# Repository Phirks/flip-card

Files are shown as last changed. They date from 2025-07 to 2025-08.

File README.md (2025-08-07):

This repo contains all files related to the flip-card project, which is a business card that runs a fluid-implicit-particle(FLIP) simulation.



The PCB design files are in the "kicad-pcb" folder. The flip-card project is inspired by mitxela's fluid simulation pendant project https://mitxela.com/projects/fluid-pendant

The fluid simulation logic is contained in a standalone crate, which is in the "fluid_sim_crate" folder. This is based off the work by Matthias Müller (https://github.com/matthias-research) and his excelent demonstrations on his youtube channel "Ten Minute Physics"

One of the more difficult features was the rechargable battery.  I found a design for a board edge usb-c port from cnlohr's tiny touch lcd project https://github.com/cnlohr/ch32v003_3digit_lcd_usb/

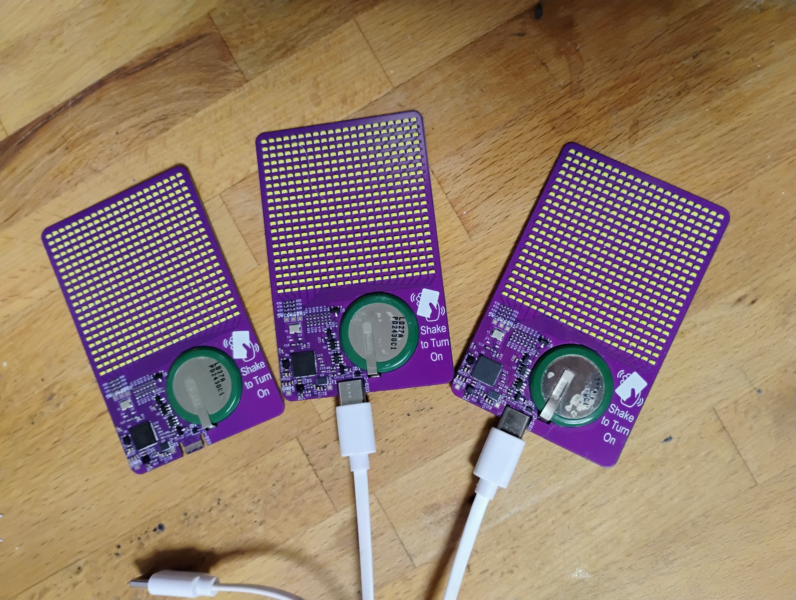
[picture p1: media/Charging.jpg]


a WASM simulator is also provided in the "sim_display" folder, which is what I use to debug issues in the simulation.

The implementation for the fluid simulation on the rp2350 is in the "flip-card_firmware" file

further details can be found in each folder's README files

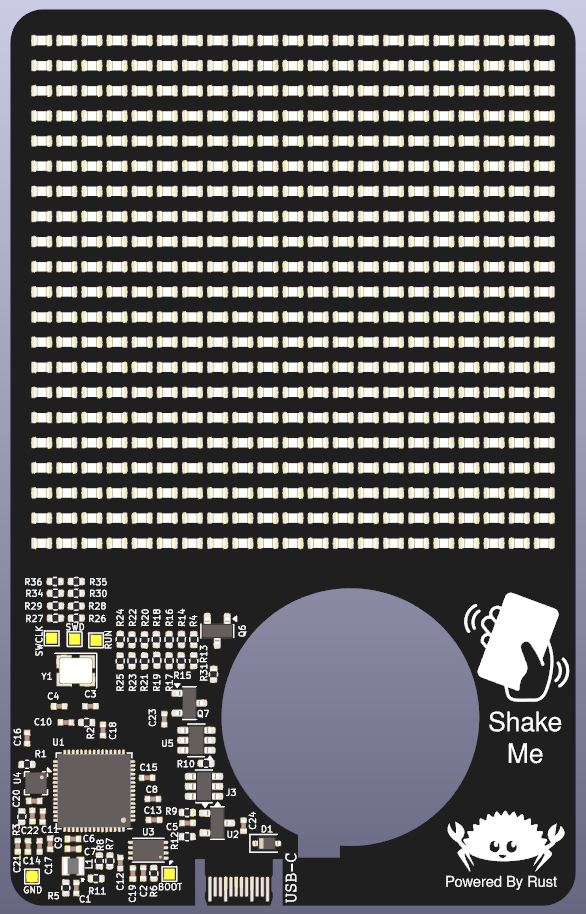
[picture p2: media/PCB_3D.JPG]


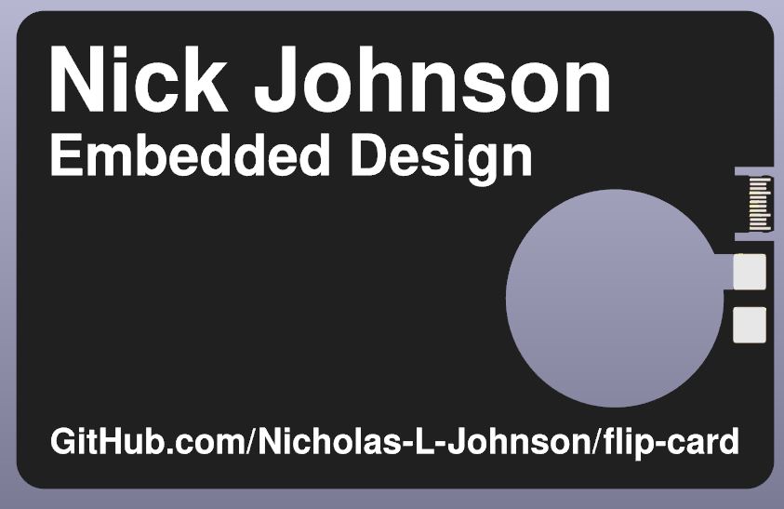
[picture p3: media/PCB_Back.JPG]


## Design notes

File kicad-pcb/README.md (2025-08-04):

Here are the PCB design files. KiCad 8.0 or higher required.

The gerber, BOM, and centroid files are in the "Production Files" directory

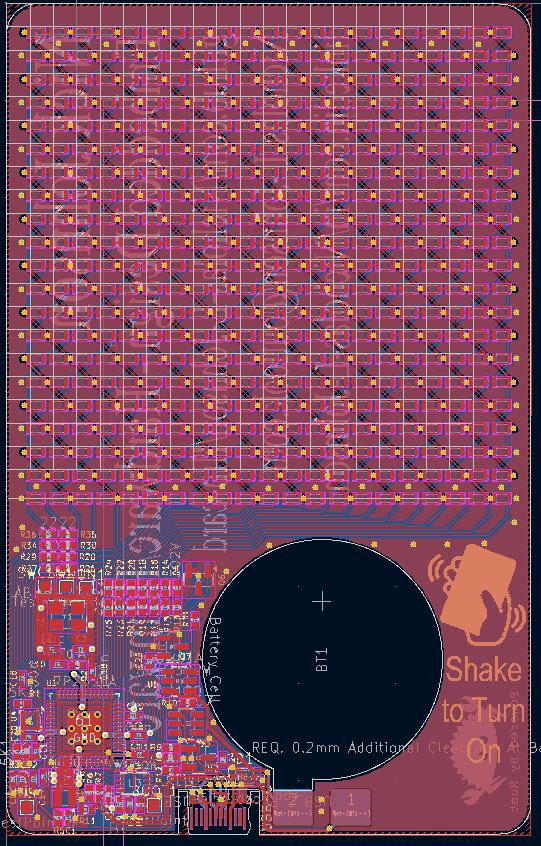
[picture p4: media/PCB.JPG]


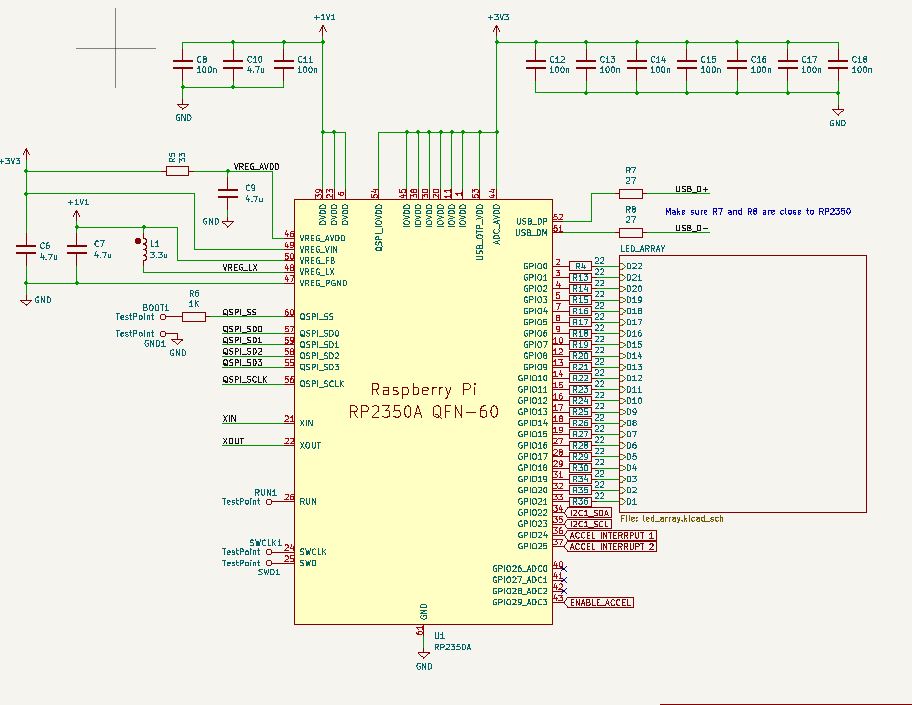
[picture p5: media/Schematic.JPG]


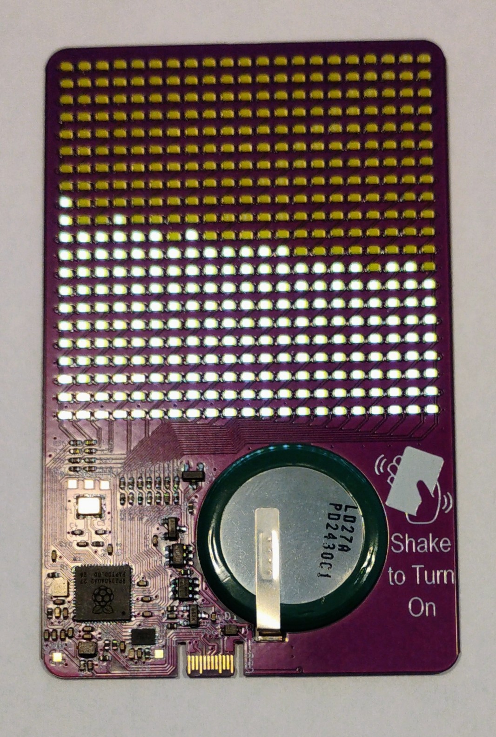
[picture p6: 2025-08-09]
media/IMG_20250809_132234644_AE.jpg

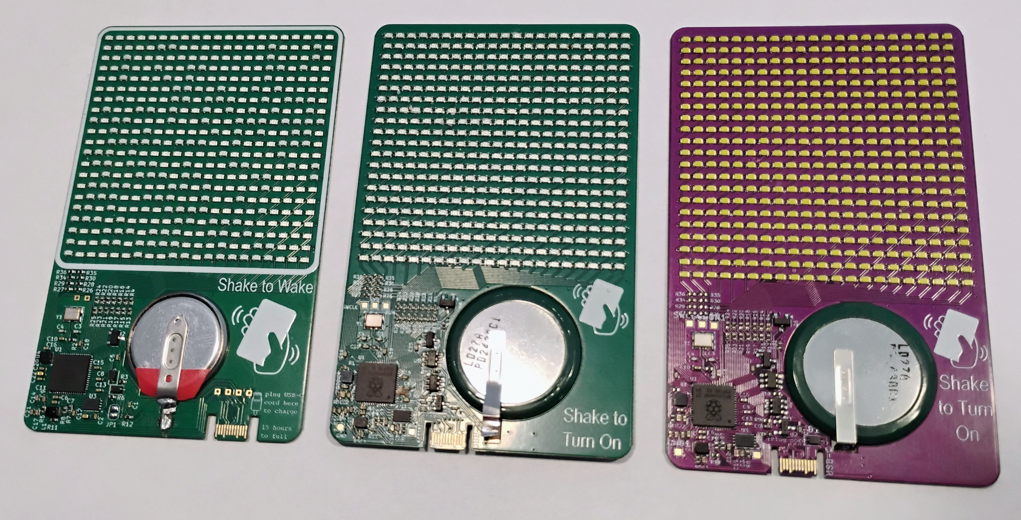
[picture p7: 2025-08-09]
media/IMG_20250809_134121077_AE.jpg

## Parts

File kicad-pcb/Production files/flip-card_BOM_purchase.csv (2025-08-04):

Comment | Designator | Footprint | JLCPCB Part +ACP/CA-optional+/wk-
1u | C1 | 402 | C2887021
100n | C2 | 402 | C5137468
15p | C3 | 402 | C326803
15p | C4 | 402 | C326803
1u | C5 | 402 | C2887021
4.7u | C6 | 402 | C380302
4.7u | C7 | 402 | C380302
100n | C8 | 402 | C5137468
4.7u | C9 | 402 | C380302
4.7u | C10 | 402 | C380302
100n | C11 | 402 | C5137468
100n | C12 | 402 | C5137468
100n | C13 | 402 | C5137468
100n | C14 | 402 | C5137468
100n | C15 | 402 | C5137468
100n | C16 | 402 | C5137468
100n | C17 | 402 | C5137468
100n | C18 | 402 | C5137468
10u | C19 | 402 | C76991
100n | C20 | 402 | C5137468
100n | C21 | 402 | C5137468
10u | C22 | 402 | C76991
100n | C23 | 402 | C5137468
1u | C24 | 402 | C2887021
Schottky Diode | D1 | SOD+AC0-323 | C146335
LED | D101 | 603 | C497920
LED | D102 | 603 | C497920
LED | D103 | 603 | C497920
LED | D104 | 603 | C497920
LED | D105 | 603 | C497920
LED | D106 | 603 | C497920
LED | D107 | 603 | C497920
LED | D108 | 603 | C497920
LED | D109 | 603 | C497920
LED | D110 | 603 | C497920
LED | D111 | 603 | C497920
LED | D112 | 603 | C497920
LED | D113 | 603 | C497920
LED | D114 | 603 | C497920
LED | D115 | 603 | C497920
LED | D116 | 603 | C497920
LED | D117 | 603 | C497920
LED | D118 | 603 | C497920
LED | D119 | 603 | C497920
LED | D120 | 603 | C497920
LED | D121 | 603 | C497920
LED | D122 | 603 | C497920
LED | D123 | 603 | C497920
LED | D124 | 603 | C497920
LED | D125 | 603 | C497920
LED | D126 | 603 | C497920
LED | D127 | 603 | C497920
LED | D128 | 603 | C497920
LED | D129 | 603 | C497920
LED | D130 | 603 | C497920
LED | D131 | 603 | C497920
LED | D132 | 603 | C497920
LED | D133 | 603 | C497920
LED | D134 | 603 | C497920
LED | D135 | 603 | C497920
LED | D136 | 603 | C497920
LED | D137 | 603 | C497920
LED | D138 | 603 | C497920
LED | D139 | 603 | C497920
LED | D140 | 603 | C497920
LED | D141 | 603 | C497920
LED | D142 | 603 | C497920
LED | D143 | 603 | C497920
LED | D144 | 603 | C497920
LED | D145 | 603 | C497920
LED | D146 | 603 | C497920
LED | D147 | 603 | C497920
LED | D148 | 603 | C497920
LED | D149 | 603 | C497920
LED | D150 | 603 | C497920
LED | D151 | 603 | C497920
LED | D152 | 603 | C497920
LED | D153 | 603 | C497920
LED | D154 | 603 | C497920
LED | D155 | 603 | C497920
LED | D156 | 603 | C497920
LED | D157 | 603 | C497920
LED | D158 | 603 | C497920
LED | D159 | 603 | C497920
LED | D160 | 603 | C497920
LED | D161 | 603 | C497920
LED | D162 | 603 | C497920
LED | D163 | 603 | C497920
LED | D164 | 603 | C497920
LED | D165 | 603 | C497920
LED | D166 | 603 | C497920
LED | D167 | 603 | C497920
LED | D168 | 603 | C497920
LED | D169 | 603 | C497920
LED | D170 | 603 | C497920
LED | D171 | 603 | C497920
LED | D172 | 603 | C497920
LED | D173 | 603 | C497920
LED | D174 | 603 | C497920
LED | D175 | 603 | C497920
LED | D176 | 603 | C497920
LED | D177 | 603 | C497920
LED | D178 | 603 | C497920
LED | D179 | 603 | C497920
LED | D180 | 603 | C497920
LED | D181 | 603 | C497920
LED | D182 | 603 | C497920
LED | D183 | 603 | C497920
LED | D184 | 603 | C497920
LED | D185 | 603 | C497920
LED | D186 | 603 | C497920
LED | D187 | 603 | C497920
LED | D188 | 603 | C497920
LED | D189 | 603 | C497920
LED | D190 | 603 | C497920
LED | D191 | 603 | C497920
LED | D192 | 603 | C497920
LED | D193 | 603 | C497920
LED | D194 | 603 | C497920
LED | D195 | 603 | C497920
LED | D196 | 603 | C497920
LED | D197 | 603 | C497920
LED | D198 | 603 | C497920
LED | D199 | 603 | C497920
LED | D200 | 603 | C497920
LED | D201 | 603 | C497920
LED | D202 | 603 | C497920
LED | D203 | 603 | C497920
LED | D204 | 603 | C497920
LED | D205 | 603 | C497920
LED | D206 | 603 | C497920
LED | D207 | 603 | C497920
LED | D208 | 603 | C497920
LED | D209 | 603 | C497920
LED | D210 | 603 | C497920
LED | D211 | 603 | C497920
LED | D212 | 603 | C497920
LED | D213 | 603 | C497920
LED | D214 | 603 | C497920
LED | D215 | 603 | C497920
LED | D216 | 603 | C497920
LED | D217 | 603 | C497920
LED | D218 | 603 | C497920
LED | D219 | 603 | C497920
LED | D220 | 603 | C497920
LED | D221 | 603 | C497920
LED | D222 | 603 | C497920
LED | D223 | 603 | C497920
LED | D224 | 603 | C497920
LED | D225 | 603 | C497920
LED | D226 | 603 | C497920
LED | D227 | 603 | C497920
LED | D228 | 603 | C497920
LED | D229 | 603 | C497920
LED | D230 | 603 | C497920
LED | D231 | 603 | C497920
LED | D232 | 603 | C497920
LED | D233 | 603 | C497920
LED | D234 | 603 | C497920
LED | D235 | 603 | C497920
LED | D236 | 603 | C497920
LED | D237 | 603 | C497920
LED | D238 | 603 | C497920
LED | D239 | 603 | C497920
LED | D240 | 603 | C497920
LED | D241 | 603 | C497920
LED | D242 | 603 | C497920
LED | D243 | 603 | C497920
LED | D244 | 603 | C497920
LED | D245 | 603 | C497920
LED | D246 | 603 | C497920
LED | D247 | 603 | C497920
LED | D248 | 603 | C497920
LED | D249 | 603 | C497920
LED | D250 | 603 | C497920
LED | D251 | 603 | C497920
LED | D252 | 603 | C497920
LED | D253 | 603 | C497920
LED | D254 | 603 | C497920
LED | D255 | 603 | C497920
LED | D256 | 603 | C497920
LED | D257 | 603 | C497920
LED | D258 | 603 | C497920
LED | D259 | 603 | C497920
LED | D260 | 603 | C497920
LED | D261 | 603 | C497920
LED | D262 | 603 | C497920
LED | D263 | 603 | C497920
LED | D264 | 603 | C497920
LED | D265 | 603 | C497920
LED | D266 | 603 | C497920
LED | D267 | 603 | C497920
LED | D268 | 603 | C497920
LED | D269 | 603 | C497920
LED | D270 | 603 | C497920
LED | D271 | 603 | C497920
LED | D272 | 603 | C497920
LED | D273 | 603 | C497920
LED | D274 | 603 | C497920
LED | D275 | 603 | C497920
LED | D276 | 603 | C497920
LED | D277 | 603 | C497920
LED | D278 | 603 | C497920
LED | D279 | 603 | C497920
LED | D280 | 603 | C497920
LED | D281 | 603 | C497920
LED | D282 | 603 | C497920
LED | D283 | 603 | C497920
LED | D284 | 603 | C497920
LED | D285 | 603 | C497920
LED | D286 | 603 | C497920
LED | D287 | 603 | C497920
LED | D288 | 603 | C497920
LED | D289 | 603 | C497920
LED | D290 | 603 | C497920
LED | D291 | 603 | C497920
LED | D292 | 603 | C497920
LED | D293 | 603 | C497920
LED | D294 | 603 | C497920
LED | D295 | 603 | C497920
LED | D296 | 603 | C497920
LED | D297 | 603 | C497920
LED | D298 | 603 | C497920
LED | D299 | 603 | C497920
LED | D300 | 603 | C497920
LED | D301 | 603 | C497920
LED | D302 | 603 | C497920
LED | D303 | 603 | C497920
LED | D304 | 603 | C497920
LED | D305 | 603 | C497920
LED | D306 | 603 | C497920
LED | D307 | 603 | C497920
LED | D308 | 603 | C497920
LED | D309 | 603 | C497920
LED | D310 | 603 | C497920
LED | D311 | 603 | C497920
LED | D312 | 603 | C497920
LED | D313 | 603 | C497920
LED | D314 | 603 | C497920
LED | D315 | 603 | C497920
LED | D316 | 603 | C497920
LED | D317 | 603 | C497920
LED | D318 | 603 | C497920
LED | D319 | 603 | C497920
LED | D320 | 603 | C497920
LED | D321 | 603 | C497920
LED | D322 | 603 | C497920
LED | D323 | 603 | C497920
LED | D324 | 603 | C497920
LED | D325 | 603 | C497920
LED | D326 | 603 | C497920
LED | D327 | 603 | C497920
LED | D328 | 603 | C497920
LED | D329 | 603 | C497920
LED | D330 | 603 | C497920
LED | D331 | 603 | C497920
LED | D332 | 603 | C497920
LED | D333 | 603 | C497920
LED | D334 | 603 | C497920
LED | D335 | 603 | C497920
LED | D336 | 603 | C497920
LED | D337 | 603 | C497920
LED | D338 | 603 | C497920
LED | D339 | 603 | C497920
LED | D340 | 603 | C497920
LED | D341 | 603 | C497920
LED | D342 | 603 | C497920
LED | D343 | 603 | C497920
LED | D344 | 603 | C497920
LED | D345 | 603 | C497920
LED | D346 | 603 | C497920
LED | D347 | 603 | C497920
LED | D348 | 603 | C497920
LED | D349 | 603 | C497920
LED | D350 | 603 | C497920
LED | D351 | 603 | C497920
LED | D352 | 603 | C497920
LED | D353 | 603 | C497920
LED | D354 | 603 | C497920
LED | D355 | 603 | C497920
LED | D356 | 603 | C497920
LED | D357 | 603 | C497920
LED | D358 | 603 | C497920
LED | D359 | 603 | C497920
LED | D360 | 603 | C497920
LED | D361 | 603 | C497920
LED | D362 | 603 | C497920
LED | D363 | 603 | C497920
LED | D364 | 603 | C497920
LED | D365 | 603 | C497920
LED | D366 | 603 | C497920
LED | D367 | 603 | C497920
LED | D368 | 603 | C497920
LED | D369 | 603 | C497920
LED | D370 | 603 | C497920
LED | D371 | 603 | C497920
LED | D372 | 603 | C497920
LED | D373 | 603 | C497920
LED | D374 | 603 | C497920
LED | D375 | 603 | C497920
LED | D376 | 603 | C497920
LED | D377 | 603 | C497920
LED | D378 | 603 | C497920
LED | D379 | 603 | C497920
LED | D380 | 603 | C497920
LED | D381 | 603 | C497920
LED | D382 | 603 | C497920
LED | D383 | 603 | C497920
LED | D384 | 603 | C497920
LED | D385 | 603 | C497920
LED | D386 | 603 | C497920
LED | D387 | 603 | C497920
LED | D388 | 603 | C497920
LED | D389 | 603 | C497920
LED | D390 | 603 | C497920
LED | D391 | 603 | C497920
LED | D392 | 603 | C497920
LED | D393 | 603 | C497920
LED | D394 | 603 | C497920
LED | D395 | 603 | C497920
LED | D396 | 603 | C497920
LED | D397 | 603 | C497920
LED | D398 | 603 | C497920
LED | D399 | 603 | C497920
LED | D400 | 603 | C497920
LED | D401 | 603 | C497920
LED | D402 | 603 | C497920
LED | D403 | 603 | C497920
LED | D404 | 603 | C497920
LED | D405 | 603 | C497920
LED | D406 | 603 | C497920
LED | D407 | 603 | C497920
LED | D408 | 603 | C497920
LED | D409 | 603 | C497920
LED | D410 | 603 | C497920
LED | D411 | 603 | C497920
LED | D412 | 603 | C497920
LED | D413 | 603 | C497920
LED | D414 | 603 | C497920
LED | D415 | 603 | C497920
LED | D416 | 603 | C497920
LED | D417 | 603 | C497920
LED | D418 | 603 | C497920
LED | D419 | 603 | C497920
LED | D420 | 603 | C497920
LED | D421 | 603 | C497920
LED | D422 | 603 | C497920
LED | D423 | 603 | C497920
LED | D424 | 603 | C497920
LED | D425 | 603 | C497920
LED | D426 | 603 | C497920
LED | D427 | 603 | C497920
LED | D428 | 603 | C497920
LED | D429 | 603 | C497920
LED | D430 | 603 | C497920
LED | D431 | 603 | C497920
LED | D432 | 603 | C497920
LED | D433 | 603 | C497920
LED | D434 | 603 | C497920
LED | D435 | 603 | C497920
LED | D436 | 603 | C497920
LED | D437 | 603 | C497920
LED | D438 | 603 | C497920
LED | D439 | 603 | C497920
LED | D440 | 603 | C497920
LED | D441 | 603 | C497920
LED | D442 | 603 | C497920
LED | D443 | 603 | C497920
LED | D444 | 603 | C497920
LED | D445 | 603 | C497920
LED | D446 | 603 | C497920
LED | D447 | 603 | C497920
LED | D448 | 603 | C497920
LED | D449 | 603 | C497920
LED | D450 | 603 | C497920
LED | D451 | 603 | C497920
LED | D452 | 603 | C497920
LED | D453 | 603 | C497920
LED | D454 | 603 | C497920
LED | D455 | 603 | C497920
LED | D456 | 603 | C497920
LED | D457 | 603 | C497920
LED | D458 | 603 | C497920
LED | D459 | 603 | C497920
LED | D460 | 603 | C497920
LED | D461 | 603 | C497920
LED | D462 | 603 | C497920
LED | D463 | 603 | C497920
LED | D464 | 603 | C497920
LED | D465 | 603 | C497920
LED | D466 | 603 | C497920
LED | D467 | 603 | C497920
LED | D468 | 603 | C497920
LED | D469 | 603 | C497920
LED | D470 | 603 | C497920
LED | D471 | 603 | C497920
LED | D472 | 603 | C497920
LED | D473 | 603 | C497920
LED | D474 | 603 | C497920
LED | D475 | 603 | C497920
LED | D476 | 603 | C497920
LED | D477 | 603 | C497920
LED | D478 | 603 | C497920
LED | D479 | 603 | C497920
LED | D480 | 603 | C497920
LED | D481 | 603 | C497920
LED | D482 | 603 | C497920
LED | D483 | 603 | C497920
LED | D484 | 603 | C497920
LED | D485 | 603 | C497920
LED | D486 | 603 | C497920
LED | D487 | 603 | C497920
LED | D488 | 603 | C497920
LED | D489 | 603 | C497920
LED | D490 | 603 | C497920
LED | D491 | 603 | C497920
LED | D492 | 603 | C497920
LED | D493 | 603 | C497920
LED | D494 | 603 | C497920
LED | D495 | 603 | C497920
LED | D496 | 603 | C497920
LED | D497 | 603 | C497920
LED | D498 | 603 | C497920
LED | D499 | 603 | C497920
LED | D500 | 603 | C497920
LED | D501 | 603 | C497920
LED | D502 | 603 | C497920
LED | D503 | 603 | C497920
LED | D504 | 603 | C497920
LED | D505 | 603 | C497920
LED | D506 | 603 | C497920
LED | D507 | 603 | C497920
LED | D508 | 603 | C497920
LED | D509 | 603 | C497920
LED | D510 | 603 | C497920
LED | D511 | 603 | C497920
LED | D512 | 603 | C497920
LED | D513 | 603 | C497920
LED | D514 | 603 | C497920
LED | D515 | 603 | C497920
LED | D516 | 603 | C497920
LED | D517 | 603 | C497920
LED | D518 | 603 | C497920
LED | D519 | 603 | C497920
LED | D520 | 603 | C497920
LED | D521 | 603 | C497920
LED | D522 | 603 | C497920
LED | D523 | 603 | C497920
LED | D524 | 603 | C497920
LED | D525 | 603 | C497920
LED | D526 | 603 | C497920
LED | D527 | 603 | C497920
LED | D528 | 603 | C497920
LED | D529 | 603 | C497920
LED | D530 | 603 | C497920
LED | D531 | 603 | C497920
LED | D532 | 603 | C497920
LED | D533 | 603 | C497920
LED | D534 | 603 | C497920
LED | D535 | 603 | C497920
LED | D536 | 603 | C497920
LED | D537 | 603 | C497920
LED | D538 | 603 | C497920
LED | D539 | 603 | C497920
LED | D540 | 603 | C497920
LED | D541 | 603 | C497920
TP4057 | J3 | SOT+AC0-23+AC0-6L | C725791
3.3u | L1 | 806 | C42411119
HL+AC0-2302V | Q6 | SOT+AC0-23 | C7431443
HL+AC0-2302V | Q7 | SOT+AC0-23 | C7431443
5K1 | R1 | 402 | C2906948
1K | R2 | 402 | C2906864
5K1 | R3 | 402 | C2906948
22 | R4 | 402 | C25092
33 | R5 | 402 | C138002
1K | R6 | 402 | C2906864
27 | R7 | 402 | C2909343
27 | R8 | 402 | C2909343
20K | R9 | 402 | C25765
100 | R10 | 402 | C2906860
5K1 | R11 | 402 | C2906948
5K1 | R12 | 402 | C2906948
22 | R13 | 402 | C25092
22 | R14 | 402 | C25092
22 | R15 | 402 | C25092
22 | R16 | 402 | C25092
22 | R17 | 402 | C25092
22 | R18 | 402 | C25092
22 | R19 | 402 | C25092
22 | R20 | 402 | C25092
22 | R21 | 402 | C25092
22 | R22 | 402 | C25092
22 | R23 | 402 | C25092
22 | R24 | 402 | C25092
22 | R25 | 402 | C25092
22 | R26 | 402 | C25092
22 | R27 | 402 | C25092
22 | R28 | 402 | C25092
22 | R29 | 402 | C25092
22 | R30 | 402 | C25092
1K | R31 | 402 | C2906864
22 | R34 | 402 | C25092
22 | R35 | 402 | C25092
22 | R36 | 402 | C25092
RP2350A | U1 | QFN+AC0-60+AC0-EP(7x7) | C42411118
REG+AF8-3.3V | U2 | SOT+AC0-23 | C5252899
ZD25WQ32CEIGR | U3 | USON+AC0-8(2x3) | C5258281
LIS2DH12TR | U4 | LGA+AC0-12(2x) | C110926
DW01A | U5 | SOT+AC0-23+AC0-6 | C42380662
ABM8+AC0-272+AC0-T3 | Y1 | 4+AC0-SMD (3.2x2.5) | C20625731

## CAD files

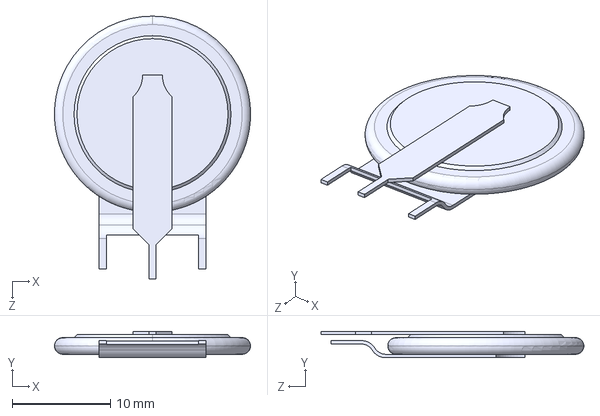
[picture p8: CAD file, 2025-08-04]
kicad-pcb/ML2020_G1A.STEP
20.0 x 2.70 x 26.8 mm

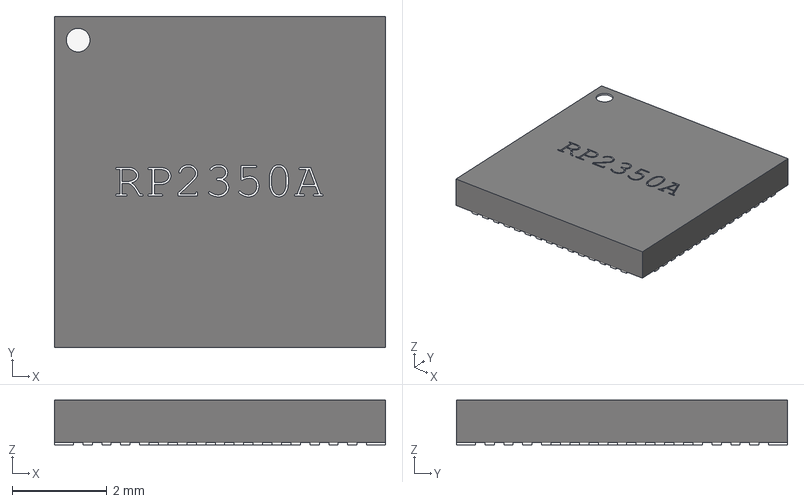
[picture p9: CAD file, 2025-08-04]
kicad-pcb/RP2350_QFN60.step
7.00 x 7.00 x 0.95 mm

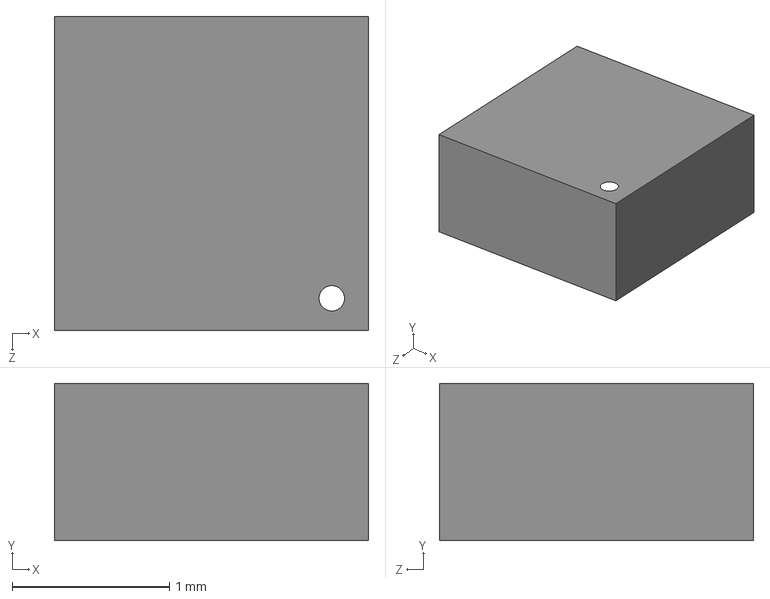
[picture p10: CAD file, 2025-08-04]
kicad-pcb/LIS2DH12TR.STEP
2.00 x 1.00 x 2.00 mm

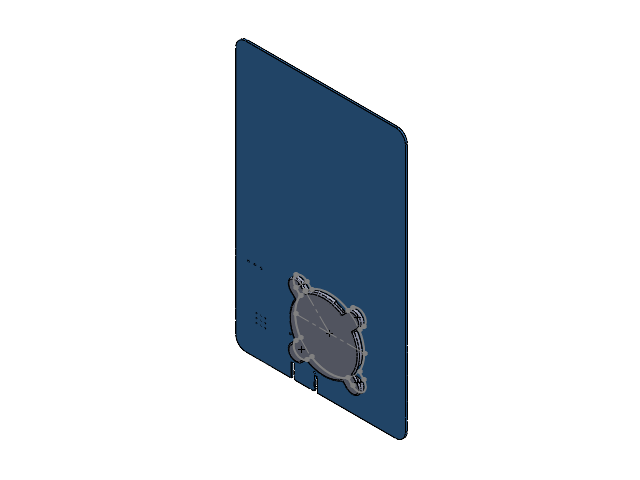
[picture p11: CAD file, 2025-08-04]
kicad-pcb/RP2350_60QFN_minimal.SLDASM
RP2350_60QFN_minimal_PCB_1.step
Part4^RP2350_60QFN_minimal
Part5^RP2350_60QFN_minimal

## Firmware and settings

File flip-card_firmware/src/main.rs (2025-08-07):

#![no_std]
#![no_main]

use core::default;

use embassy_executor::{Executor, Spawner};
use embassy_futures::select::{Either::First, select};
use embassy_rp::bind_interrupts;
use embassy_rp::gpio;
use embassy_rp::gpio::DormantWakeConfig;
use embassy_rp::gpio::Input;
use embassy_rp::gpio::Pull;
use heapless::Vec;
// use embassy_rp::gpio::{Input, Pull};
use embassy_rp::clocks::{ClockConfig, CoreVoltage, clk_sys_freq, core_voltage};
use embassy_rp::i2c;
use embassy_rp::i2c::I2c;
use embassy_rp::i2c::InterruptHandler as I2C_InterruptHandler;
use embassy_rp::multicore::{Stack, spawn_core1};
use embassy_rp::peripherals::*;
use embassy_rp::pio::program::pio_asm;
use embassy_rp::pio::{Config, InterruptHandler, Pio, ShiftConfig, ShiftDirection};
use embassy_rp::watchdog::*;
use embassy_sync::blocking_mutex::raw::CriticalSectionRawMutex;
use embassy_time::Duration;
use embassy_time::Timer;
use fixed::traits::ToFixed;
use fixed_macro::types::U56F8;
use fluid_sim::FluidSimulation::Scene;
use gpio::{Level, Output};

use static_cell::StaticCell;
// use {defmt_rtt as _, panic_probe as _};

static mut CORE1_STACK: Stack<262144> = Stack::new();
static EXECUTOR0: StaticCell<Executor> = StaticCell::new();
static EXECUTOR1: StaticCell<Executor> = StaticCell::new();
// static CHANNEL: Channel<CriticalSectionRawMutex, LedState, 1> = Channel::new();

static BIT21: u32 = 0b00000000001000000000000000000000; // pinout 19 1
static BIT20: u32 = 0b00000000000100000000000000000000; // pinout 19 2
static BIT19: u32 = 0b00000000000010000000000000000000; // pinout 19 3
static BIT18: u32 = 0b00000000000001000000000000000000; // pinout 18 4
static BIT17: u32 = 0b00000000000000100000000000000000; // pinout 17 5
static BIT16: u32 = 0b00000000000000010000000000000000; // pinout 16 6
static BIT15: u32 = 0b00000000000000001000000000000000; // pinout 15 7
static BIT14: u32 = 0b00000000000000000100000000000000; // pinout 14 8
static BIT13: u32 = 0b00000000000000000010000000000000; // pinout 13 9
static BIT12: u32 = 0b00000000000000000001000000000000; // pinout 12 10
static BIT11: u32 = 0b00000000000000000000100000000000; // pinout 11 11
static BIT10: u32 = 0b00000000000000000000010000000000; // pinout 10 12
static BIT9: u32 = 0b00000000000000000000001000000000; // pinout 9 13
static BIT8: u32 = 0b00000000000000000000000100000000; // pinout 8 14
static BIT7: u32 = 0b00000000000000000000000010000000; // pinout 7 15
static BIT6: u32 = 0b00000000000000000000000001000000; // pinout 6 16
static BIT5: u32 = 0b00000000000000000000000000100000; // pinout 5 17
static BIT4: u32 = 0b00000000000000000000000000010000; // pinout 4 18
static BIT3: u32 = 0b00000000000000000000000000001000; // pinout 3 19
static BIT2: u32 = 0b00000000000000000000000000000100; // pinout 2 20
static BIT1: u32 = 0b00000000000000000000000000000010; // pinout 1 21
static BIT0: u32 = 0b00000000000000000000000000000001; // pinout 1 21

static FRAME_DATA_SIGNAL: embassy_sync::signal::Signal<CriticalSectionRawMutex, [[bool; 21]; 21]> =
    embassy_sync::signal::Signal::new();

static ACCEL_DATA_SIGNAL: embassy_sync::signal::Signal<CriticalSectionRawMutex, [f32; 2]> =
    embassy_sync::signal::Signal::new();

static BITS: [u32; 22] = [
    BIT21, BIT20, BIT19, BIT18, BIT17, BIT16, BIT15, BIT14, BIT13, BIT12, BIT11, BIT10, BIT9, BIT8,
    BIT7, BIT6, BIT5, BIT4, BIT3, BIT2, BIT1, BIT0,
];

static LOOKUP_TABLE: [[usize; 21]; 21] = [
    [
        416, 481, 373, 435, 327, 389, 281, 343, 235, 297, 189, 251, 143, 205, 097, 159, 051, 113,
        005, 067, 025,
    ],
    [
        459, 372, 479, 329, 433, 283, 387, 237, 341, 191, 295, 145, 249, 099, 203, 053, 157, 007,
        111, 027, 068,
    ],
    [
        370, 457, 328, 477, 285, 431, 239, 385, 193, 339, 147, 293, 101, 247, 055, 201, 009, 155,
        029, 112, 071,
    ],
    [
        413, 326, 455, 284, 475, 241, 429, 195, 383, 149, 337, 103, 291, 057, 245, 011, 199, 031,
        156, 073, 114,
    ],
    [
        324, 411, 282, 453, 240, 473, 197, 427, 151, 381, 105, 335, 059, 289, 013, 243, 033, 200,
        075, 158, 117,
    ],
    [
        367, 280, 409, 238, 451, 196, 471, 153, 425, 107, 379, 061, 333, 015, 287, 035, 244, 077,
        202, 119, 160,
    ],
    [
        278, 365, 236, 407, 194, 449, 152, 469, 109, 423, 063, 377, 017, 331, 037, 288, 079, 246,
        121, 204, 163,
    ],
    [
        321, 234, 363, 192, 405, 150, 447, 108, 467, 065, 421, 019, 375, 039, 332, 081, 290, 123,
        248, 165, 206,
    ],
    [
        232, 319, 190, 361, 148, 403, 106, 445, 064, 465, 021, 419, 041, 376, 083, 334, 125, 292,
        167, 250, 209,
    ],
    [
        275, 188, 317, 146, 359, 104, 401, 062, 443, 020, 463, 043, 420, 085, 378, 127, 336, 169,
        294, 211, 252,
    ],
    [
        186, 273, 144, 315, 102, 357, 060, 399, 018, 441, 042, 464, 087, 422, 129, 380, 171, 338,
        213, 296, 255,
    ],
    [
        229, 142, 271, 100, 313, 058, 355, 016, 397, 040, 442, 086, 466, 131, 424, 173, 382, 215,
        340, 257, 298,
    ],
    [
        140, 227, 098, 269, 056, 311, 014, 353, 038, 398, 084, 444, 130, 468, 175, 426, 217, 384,
        259, 342, 301,
    ],
    [
        183, 096, 225, 054, 267, 012, 309, 036, 354, 082, 400, 128, 446, 174, 470, 219, 428, 261,
        386, 303, 344,
    ],
    [
        094, 181, 052, 223, 010, 265, 034, 310, 080, 356, 126, 402, 172, 448, 218, 472, 263, 430,
        305, 388, 347,
    ],
    [
        137, 050, 179, 008, 221, 032, 266, 078, 312, 124, 358, 170, 404, 216, 450, 262, 474, 307,
        432, 349, 390,
    ],
    [
        048, 135, 006, 177, 030, 222, 076, 268, 122, 314, 168, 360, 214, 406, 260, 452, 306, 476,
        351, 434, 393,
    ],
    [
        091, 004, 133, 028, 178, 074, 224, 120, 270, 166, 316, 212, 362, 258, 408, 304, 454, 350,
        478, 395, 436,
    ],
    [
        002, 089, 026, 134, 072, 180, 118, 226, 164, 272, 210, 318, 256, 364, 302, 410, 348, 456,
        394, 480, 439,
    ],
    [
        045, 024, 090, 070, 136, 116, 182, 162, 228, 208, 274, 254, 320, 300, 366, 346, 412, 392,
        458, 438, 482,
    ],
    [
        023, 046, 069, 092, 115, 138, 161, 184, 207, 230, 253, 276, 299, 322, 345, 368, 391, 414,
        437, 460, 461,
    ],
];

struct Screen {
    yx_grid: [[bool; 21]; 21],
    yx_lock_grid: [[bool; 21]; 21],
    index_grid: [bool; 484],
    out_array: [u32; 506],
    out_array_2: Vec<u32, 1452>,
}
impl Screen {
    fn fill_index(&mut self) {
        self.index_grid = [false; 484];
        for y in 0..21 {
            for x in 0..21 {
                if self.yx_grid[y][x] {
                    self.index_grid[LOOKUP_TABLE[y][x]] = true
                }
            }
        }
    }
    fn post_process(&mut self) {
        let mut temp_yx_lock_grid = [[false; 21]; 21];
        for i in 0..self.yx_grid.len() {
            for j in 0..self.yx_grid[0].len() {
                if self.yx_grid[i][j] {
                    if i == 20 || self.yx_grid[i + 1][j] {
                        if i == 0 || self.yx_grid[i - 1][j] {
                            if j == 20 || self.yx_grid[i][j + 1] {
                                if j == 0 || self.yx_grid[i][j - 1] {
                                    temp_yx_lock_grid[i][j] = true
                                }
                            }
                        }
                    }
                }
            }
        }
        for i in 0..self.yx_grid.len() {
            for j in 0..self.yx_grid[0].len() {
                if self.yx_lock_grid[i][j] {
                    if i == 20 || self.yx_grid[i + 1][j] {
                        if i == 0 || self.yx_grid[i - 1][j] {
                            if j == 20 || self.yx_grid[i][j + 1] {
                                if j == 0 || self.yx_grid[i][j - 1] {
                                    self.yx_grid[i][j] = true;
                                }
                            }
                        }
                    }
                }
            }
        }
        self.yx_lock_grid = temp_yx_lock_grid;
    }
    fn make_output(&mut self) {
        self.out_array = [0; 506];
        let mut index = 0;
        let mut counter = 0;

        for i in 0..BITS.len() {
            self.out_array[counter] = BITS[i];
            index += 1;
            counter += 1;
            for j in 0..BITS.len() {
                if i != j {
                    if self.index_grid[index] {
                        self.out_array[counter] = BITS[i] | BITS[j];
                    }
                    index += 1;
                    counter += 1;
                }
            }
            // counter += 1;
        }
    }
    fn make_output_2(&mut self) {
        self.out_array_2 = Vec::new();
        let mut index = 0;
        for i in 0..BITS.len() {
            index += 1;
            for j in 0..BITS.len() {
                if i != j {
                    if self.index_grid[index] {
                        self.out_array_2.push(BITS[i]).unwrap();
                        self.out_array_2.push(BITS[i] | BITS[j]).unwrap();
                        self.out_array_2.push(0).unwrap();
                    }
                    index += 1;
                }
            }
        }
        if self.index_grid[461] {
            self.out_array_2.push(BITS[21]).unwrap();
            self.out_array_2.push(BITS[21] | BITS[20]).unwrap();
            self.out_array_2.push(0).unwrap();
        }
    }
    fn _disp_num(&mut self, num: usize, yloc: usize, xloc: usize) {
        let ymin = yloc;
        let ymax = yloc + 7;
        let xmin = xloc;
        let xmax = xloc + 5;

        for y in ymin..ymax {
            for x in xmin..xmax {
                self.yx_grid[y][x] = false;
            }
        }
        match num {
            0 => {
                self.yx_grid[ymin + 1][xmin + 1] = true;
                self.yx_grid[ymin + 2][xmin + 1] = true;
                self.yx_grid[ymin + 3][xmin + 1] = true;
                self.yx_grid[ymin + 4][xmin + 1] = true;
                self.yx_grid[ymin + 5][xmin + 1] = true;

                self.yx_grid[ymin + 1][xmin + 2] = true;
                //self.yx_grid[ymin +3][xmin + 2] = true;
                self.yx_grid[ymin + 5][xmin + 2] = true;

                self.yx_grid[ymin + 1][xmin + 3] = true;
                self.yx_grid[ymin + 2][xmin + 3] = true;
                self.yx_grid[ymin + 3][xmin + 3] = true;
                self.yx_grid[ymin + 4][xmin + 3] = true;
                self.yx_grid[ymin + 5][xmin + 3] = true;
            }
            1 => {
                // self.yx_grid[ymin + 1][xmin + 1] = true;
                // self.yx_grid[ymin + 2][xmin + 1] = true;
                // self.yx_grid[ymin + 3][xmin + 1] = true;
                // self.yx_grid[ymin + 4][xmin + 1] = true;
                // self.yx_grid[ymin + 5][xmin + 1] = true;

                // self.yx_grid[ymin + 1][xmin + 2] = true;
                // self.yx_grid[ymin +3][xmin + 2] = true;
                // self.yx_grid[ymin + 5][xmin + 2] = true;

                self.yx_grid[ymin + 1][xmin + 3] = true;
                self.yx_grid[ymin + 2][xmin + 3] = true;
                self.yx_grid[ymin + 3][xmin + 3] = true;
                self.yx_grid[ymin + 4][xmin + 3] = true;
                self.yx_grid[ymin + 5][xmin + 3] = true;
            }
            2 => {
                self.yx_grid[ymin + 1][xmin + 1] = true;
                // self.yx_grid[ymin + 2][xmin + 1] = true;
                self.yx_grid[ymin + 3][xmin + 1] = true;
                self.yx_grid[ymin + 4][xmin + 1] = true;
                self.yx_grid[ymin + 5][xmin + 1] = true;

                self.yx_grid[ymin + 1][xmin + 2] = true;
                self.yx_grid[ymin + 3][xmin + 2] = true;
                self.yx_grid[ymin + 5][xmin + 2] = true;

                self.yx_grid[ymin + 1][xmin + 3] = true;
                self.yx_grid[ymin + 2][xmin + 3] = true;
                self.yx_grid[ymin + 3][xmin + 3] = true;
                // self.yx_grid[ymin + 4][xmin + 3] = true;
                self.yx_grid[ymin + 5][xmin + 3] = true;
            }
            3 => {
                self.yx_grid[ymin + 1][xmin + 1] = true;
                // self.yx_grid[ymin + 2][xmin + 1] = true;
                self.yx_grid[ymin + 3][xmin + 1] = true;
                // self.yx_grid[ymin + 4][xmin + 1] = true;
                self.yx_grid[ymin + 5][xmin + 1] = true;

                self.yx_grid[ymin + 1][xmin + 2] = true;
                self.yx_grid[ymin + 3][xmin + 2] = true;
                self.yx_grid[ymin + 5][xmin + 2] = true;

                self.yx_grid[ymin + 1][xmin + 3] = true;
                self.yx_grid[ymin + 2][xmin + 3] = true;
                self.yx_grid[ymin + 3][xmin + 3] = true;
                self.yx_grid[ymin + 4][xmin + 3] = true;
                self.yx_grid[ymin + 5][xmin + 3] = true;
            }
            4 => {
                self.yx_grid[ymin + 1][xmin + 1] = true;
                self.yx_grid[ymin + 2][xmin + 1] = true;
                self.yx_grid[ymin + 3][xmin + 1] = true;
                // self.yx_grid[ymin + 4][xmin + 1] = true;
                // self.yx_grid[ymin + 5][xmin + 1] = true;

                // self.yx_grid[ymin + 1][xmin + 2] = true;
                self.yx_grid[ymin + 3][xmin + 2] = true;
                // self.yx_grid[ymin + 5][xmin + 2] = true;
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
async fn main(_spawner: Spawner) {
    // define all the peripherals and pins
    let mut config =
        embassy_rp::config::Config::new(ClockConfig::system_freq(200_000_000).unwrap());
    config.clocks.core_voltage = CoreVoltage::V1_15;
    let p = embassy_rp::init(config);
    let mut i2c: I2c<'static, I2C1, i2c::Async> =
        embassy_rp::i2c::I2c::new_async(p.I2C1, p.PIN_23, p.PIN_22, Irqs, Default::default());
    let watchdog = Watchdog::new(p.WATCHDOG);
    let mut enable_accel = Output::new(p.PIN_29, Level::Low);
    let pio: embassy_rp::Peri<'static, PIO0> = p.PIO0; //this PIO object is one of the 4 PIO peripherals
    let dma_out_ref: embassy_rp::Peri<'static, DMA_CH0> = p.DMA_CH0;
    let mut accel_interrupt_1 = Input::new(p.PIN_24, Pull::Up);
    let mut accel_interrupt_2 = Input::new(p.PIN_25, Pull::Up);
    // Timer::after_millis(10).await;

    // start up the peripherals
    let sm = setup_pio_2(
        pio, p.PIN_0, p.PIN_1, p.PIN_2, p.PIN_3, p.PIN_4, p.PIN_5, p.PIN_6, p.PIN_7, p.PIN_8,
        p.PIN_9, p.PIN_10, p.PIN_11, p.PIN_12, p.PIN_13, p.PIN_14, p.PIN_15, p.PIN_16, p.PIN_17,
        p.PIN_18, p.PIN_19, p.PIN_20, p.PIN_21,
    );
    enable_accel.set_high();
    let screen = Screen {
        yx_grid: [[false; 21]; 21],
        yx_lock_grid: [[false; 21]; 21],
        index_grid: [false; 484],
        out_array: [0; 506],
        out_array_2: Vec::new(),
    };

    // spawn background tasks

    spawn_core1(
        p.CORE1,
        unsafe { &mut *core::ptr::addr_of_mut!(CORE1_STACK) },
        move || {
            let executor1 = EXECUTOR1.init(Executor::new());
            executor1.run(|spawner| spawner.spawn(simulation_update()).unwrap())
        },
    );

    let executor0 = EXECUTOR0.init(Executor::new());
    executor0.run(|spawner| {
        spawner
            .spawn(monitor_accelerometer(
                i2c,
                accel_interrupt_1,
                accel_interrupt_2,
                enable_accel,
            ))
            .unwrap();
        spawner
            .spawn(drive_screen(watchdog, screen, sm, dma_out_ref))
            .unwrap()
    });
}

#[embassy_executor::task(pool_size = 1)]
async fn drive_screen(
    mut watchdog: Watchdog,
    mut screen: Screen,
    mut sm: embassy_rp::pio::StateMachine<'static, PIO0, 0>,
    mut dma_out_ref: embassy_rp::Peri<'static, DMA_CH0>,
) {
    let tx = sm.tx();
    let mut frame_count: u128 = 0;
    FRAME_DATA_SIGNAL.wait().await;
    watchdog.start(Duration::from_millis(500));
    loop {
        Timer::after_millis(1).await;
        watchdog.feed();
        if FRAME_DATA_SIGNAL.signaled() {
            screen.yx_grid = FRAME_DATA_SIGNAL.wait().await;
            frame_count = 0;
        } else {
            frame_count += 1;
        }
        screen.post_process();
        screen.fill_index();
        // screen.make_output();
        screen.make_output_2();
        tx.dma_push(dma_out_ref.reborrow(), &screen.out_array_2, false)
            .await;
        if frame_count >= 30 {
            // flash.blocking_write(reset_count_location, &[10u8]);
            // embassy_rp::rom_data::reboot(0x0002, 1, 0x00, 0x01); // reboot to BOOTSEL
            Timer::after_millis(3000).await;
        }
    }
}

#[embassy_executor::task(pool_size = 1)]
async fn monitor_accelerometer(
    mut i2c: I2c<'static, I2C1, i2c::Async>,
    mut int1: Input<'static>,
    mut int2: Input<'static>,
    mut enable_accel: Output<'static>,
) {
    //setup accelerometer
    let addr: u8 = 0x18;
    let dt: f32 = 1.0 / 100.0; // 1/Hz,
    let accel_scale_max: f32 = 9.81 * 8.0; // m/s²
    let mut xh: [u8; 1] = [0];
    i2c.blocking_write(addr, &[0x24, 0x08]).unwrap(); // CTRL_REG5, reboot chip
    i2c.blocking_write(addr, &[0x24, 0x80]).unwrap(); // CTRL_REG1, turn on, enable xyz
    Timer::after_millis(100).await;
    i2c.blocking_write(addr, &[0x20, 0x77]).unwrap(); // CTRL_REG1, turn on, enable xyz
    i2c.blocking_write(addr, &[0x21, 0x00]).unwrap(); // CTRL_REG2, high pass filter off
    i2c.blocking_write(addr, &[0x22, 0x80]).unwrap(); // CTRL_REG3, click to INT1 pin
    i2c.blocking_write(addr, &[0x23, 0x20]).unwrap(); // CTRL_REG4, FS = 8G
    // i2c.blocking_write(addr, &[0x24, 0x08]).unwrap(); // CTRL_REG5, latch INT pin 1
    i2c.blocking_write(addr, &[0x32, 0x0A]).unwrap(); // INT1_THS, Threshold = 250 mg
    i2c.blocking_write(addr, &[0x33, 0x7F]).unwrap(); // INT1_DURATION, Duration = 0
    i2c.blocking_write(addr, &[0x38, 0x22]).unwrap(); // CLICK_CFG
    i2c.blocking_write(addr, &[0x39, 0x27]).unwrap(); // CLICK_SRC
    i2c.blocking_write(addr, &[0x3A, 0x40]).unwrap(); // CLICK_THS
    i2c.blocking_write(addr, &[0x3B, 0x20]).unwrap(); // TIME_LIMIT
    i2c.blocking_write(addr, &[0x3C, 0x2F]).unwrap(); // TIME_LATENCY
    i2c.blocking_write(addr, &[0x3D, 0x30]).unwrap(); // TIME WINDOW
    // i2c.blocking_write(addr, &[0x30, 0x02]).unwrap(); // INT1_CFG, enable xh and yh interrupts
    // int1.wait_for_high().await;
    enable_accel.set_low();
    let dormant_config = DormantWakeConfig {
        edge_high: false,
        edge_low: false,
        level_high: true,
        level_low: false,
    };
    let wake = int1.dormant_wake(dormant_config.clone());
    let wake2 = int2.dormant_wake(dormant_config.clone());
    embassy_rp::clocks::dormant_sleep();
    drop(wake);
    drop(wake2);

    enable_accel.set_high();
    // i2c.blocking_write(addr, &[0x24, 0x80]).unwrap(); // CTRL_REG5, reboot chip
    i2c.blocking_write(addr, &[0x20, 0x57]).unwrap(); // CTRL_REG1, turn on, enable xy
    i2c.blocking_write(addr, &[0x23, 0x20]).unwrap(); // CTRL_REG1, turn on, enable xy
    //read accelerometer
    let mut yh: [u8; 1] = [0];
    let mut x_val: i8;
    let mut y_val: i8;
    let mut normalized_x_accel: f32;
    let mut normalized_y_accel: f32;
    let mut y_counter: usize = 0;
    let mut frame_count = 0;
    loop {
        Timer::after_millis(5).await;
        // if frame_count > 14 {
        //     embassy_rp::rom_data::reboot(0x0002, 1, 0x00, 0x01); // reboot to BOOTSEL
        // } else {
        //     frame_count += 1;
        // }
        i2c.write_read_async(addr, [0x29], &mut xh).await.unwrap(); // read accel data
        i2c.write_read_async(addr, [0x2B], &mut yh).await.unwrap(); // read accel data
        x_val = xh[0] as i8;
        y_val = yh[0] as i8;
        normalized_x_accel = (0.7 * accel_scale_max * (x_val as f32) / 128.0) / dt;
        normalized_y_accel = (0.7 * accel_scale_max * (y_val as f32) / 128.0) / dt;

        if y_val > 10 {
            y_counter += 1;
            if y_counter > 1000 {
                // embassy_rp::rom_data::reboot(0x0002, 1, 0x00, 0x01); // reboot to BOOTSEL
                Timer::after_millis(3000).await;
            }
        } else {
            if y_counter > 0 {
                y_counter -= 1;
            }
        }

        ACCEL_DATA_SIGNAL.signal([normalized_x_accel, -normalized_y_accel]);
    }
}

#[embassy_executor::task]
async fn simulation_update() {
    let mut scene = Scene::setupScene(500);
    ACCEL_DATA_SIGNAL.wait().await;
    let mut frame_count = 0;
    let mut miss_count = 0;
    let mut shake_count = 0;
    loop {
        if let First(accel_measurment) =
            select(ACCEL_DATA_SIGNAL.wait(), Timer::after_millis(10)).await
        {
            miss_count = 0;
            scene.set_gravity(accel_measurment);
            if accel_measurment[1] > 1000.0 || accel_measurment[1] < -1000.0 {
                shake_count += 100;
                if shake_count > 400 {
                    scene.particle_add(500, 500);
                }
            } else if shake_count > 0 {
                shake_count -= 1;
            }
        } else {
            miss_count += 1
        }
        if frame_count > 1000 {
            if frame_count % 10 == 0 {
                scene.particle_add(-1, 500);
            }
        }

        if !scene.is_paused() && scene.get_num_particles() > 0 && miss_count < 10 {
            frame_count += 1;
            scene.simulate();
            FRAME_DATA_SIGNAL.signal(scene.get_output());
        } else {
            // ACCEL_DATA_SIGNAL.wait().await;
        }
    }
}
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

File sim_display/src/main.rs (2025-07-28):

use std::cell::RefCell;
use std::f32::consts::PI;
use std::rc::Rc;

use fluid_sim::FluidSimulation::*;
use wasm_bindgen::JsCast;
use wasm_bindgen::prelude::*;
use web_sys::{HtmlCanvasElement, WebGlRenderingContext as GL, WebGlRenderingContext, window};
use yew::{Component, Context, Html, NodeRef, html};

// Wrap gl in Rc (Arc for multi-threaded) so it can be injected into the render-loop closure.
pub struct App {
    node_ref: NodeRef,
}

impl Component for App {
    type Message = ();
    type Properties = ();

    fn create(_ctx: &Context<Self>) -> Self {
        Self {
            node_ref: NodeRef::default(),
        }
    }

    fn view(&self, _ctx: &Context<Self>) -> Html {
        html! {
            <canvas width="600" height="600" ref={self.node_ref.clone()} />
        }
    }

    fn rendered(&mut self, _ctx: &Context<Self>, first_render: bool) {
        // Only start the render loop if it's the first render
        // There's no loop cancellation taking place, so if multiple renders happen,
        // there would be multiple loops running. That doesn't *really* matter here because
        // there's no props update and no SSR is taking place, but it is something to keep in
        // consideration
        if !first_render {
            return;
        }
        // Once rendered, store references for the canvas and GL context. These can be used for
        // resizing the rendering area when the window or canvas element are resized, as well as
        // for making GL calls.
        let canvas = self.node_ref.cast::<HtmlCanvasElement>().unwrap();
        let gl: GL = canvas
            .get_context("webgl")
            .unwrap()
            .unwrap()
            .dyn_into()
            .unwrap();
        Self::render_gl(gl);
    }
}

impl App {
    fn request_animation_frame(f: &Closure<dyn FnMut()>) {
        window()
            .unwrap()
            .request_animation_frame(f.as_ref().unchecked_ref())
            .expect("should register `requestAnimationFrame` OK");
    }

    fn render_gl(gl: WebGlRenderingContext) {
        let mut scene = Scene::setupScene(400);
        // This should log only once -- not once per frame

        let mut timestamp = 0.0;

        let vert_code = include_str!("./basic.vert");
        let frag_code = include_str!("./basic.frag");

        // This list of vertices will draw two triangles to cover the entire canvas.
        let vertices: Vec<f32> = Vec::new();
        let vertex_buffer = gl.create_buffer().unwrap();
        let verts = js_sys::Float32Array::from(vertices.as_slice());

        gl.bind_buffer(GL::ARRAY_BUFFER, Some(&vertex_buffer));
        gl.buffer_data_with_array_buffer_view(GL::ARRAY_BUFFER, &verts, GL::STATIC_DRAW);

        let vert_shader = gl.create_shader(GL::VERTEX_SHADER).unwrap();
        gl.shader_source(&vert_shader, vert_code);
        gl.compile_shader(&vert_shader);

        let frag_shader = gl.create_shader(GL::FRAGMENT_SHADER).unwrap();
        gl.shader_source(&frag_shader, frag_code);
        gl.compile_shader(&frag_shader);

        let shader_program = gl.create_program().unwrap();
        gl.attach_shader(&shader_program, &vert_shader);
        gl.attach_shader(&shader_program, &frag_shader);
        gl.link_program(&shader_program);

        gl.use_program(Some(&shader_program));

        // Attach the position vector as an attribute for the GL context.
        let position = gl.get_attrib_location(&shader_program, "a_position") as u32;
        gl.vertex_attrib_pointer_with_i32(position, 2, GL::FLOAT, false, 0, 0);
        gl.enable_vertex_attrib_array(position);

        // Attach the time as a uniform for the GL context.
        let time = gl.get_uniform_location(&shader_program, "u_time");
        gl.uniform1f(time.as_ref(), timestamp as f32);

        gl.draw_arrays(GL::TRIANGLES, 0, 6);

        // Gloo-render's request_animation_frame has this extra closure
        // wrapping logic running every frame, unnecessary cost.
        // Here constructing the wrapped closure just once.

        let cb = Rc::new(RefCell::new(None));

        *cb.borrow_mut() = Some(Closure::wrap(Box::new({
            let cb = cb.clone();
            move || {
                scene.set_gravity([-10.0, -10.0]);
                scene.simulate();
                // This should repeat every frame
                timestamp += 20.0;
                let mut vertices: Vec<f32> = Vec::new();
                let mut count = 0;
                make_rectangle(&mut vertices, &mut count, 1.685, 0.005, 0.0, -0.84);
                make_rectangle(&mut vertices, &mut count, 1.685, 0.005, 0.0, 0.84);
                make_rectangle(&mut vertices, &mut count, 0.005, 1.685, -0.84, 0.0);
                make_rectangle(&mut vertices, &mut count, 0.005, 1.685, 0.84, 0.0);
                for i in 0..scene.fluid.numParticles {
                    make_circle(
                        &mut vertices,
                        &mut count,
                        0.04*0.6,
                        30,
                        scene.fluid.particlePos[2 * i as usize],
                        scene.fluid.particlePos[2 * i as usize + 1],
                    );
                }
                let verts = js_sys::Float32Array::from(vertices.as_slice());
                gl.buffer_data_with_array_buffer_view(GL::ARRAY_BUFFER, &verts, GL::STATIC_DRAW);
                gl.uniform1f(time.as_ref(), timestamp as f32);
                gl.draw_arrays(GL::TRIANGLES, 0, count);
                App::request_animation_frame(cb.borrow().as_ref().unwrap());
            }
        }) as Box<dyn FnMut()>));

        App::request_animation_frame(cb.borrow().as_ref().unwrap());
    }
}

fn main() {
    yew::Renderer::<App>::new().render();
}

fn make_circle(
    buffer_vec: &mut Vec<f32>,
    count: &mut i32,
    radius: f32,
    num_points: i32,
    center_y: f32,
    center_x: f32,
) {
    let center_y = (center_y / 12.5) - 0.84;
    let center_x = (center_x / 12.5) - 0.84;
    for i in 0..num_points {
        let angle = 2.0 * PI * i as f32 / num_points as f32;
        let angle2 = 2.0 * PI * (i + 1) as f32 / num_points as f32;
        buffer_vec.push(center_x + radius * angle.cos());
        buffer_vec.push(center_y + radius * angle.sin());
        buffer_vec.push(center_x);
        buffer_vec.push(center_y);
        buffer_vec.push(center_x + radius * angle2.cos());
        buffer_vec.push(center_y + radius * angle2.sin());
    }
    *count += num_points * 3;
}
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

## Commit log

2025-08-01 setup an await shutdown, still uses a lot of power
2025-08-04 Added the PCB
    [LIS2DH12TR.STEP, ML2020_G1A.STEP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]
2025-08-07 added power saving where fluid drains
2025-08-07 changed charging image name
